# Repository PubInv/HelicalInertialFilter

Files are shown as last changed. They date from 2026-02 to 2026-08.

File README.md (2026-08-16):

# Helical Inertial Filter design

Through this project, we aim to design a filter that removes dust from low-velocity gas-solid suspensions which are characteristic of lunar surface systems, but could be used for regular medical purposes as well.

We have produced a physical helical filter prototype using 405nm UV-cured transparent resin surface-treated with polycrylic spray. We also tested the filter by installing one end in the “Particle Zenith Device”, described below, and the other end in an industrial shop vacuum. 

Currently, we are looking for additional volunteers with backgrounds in mechanical engineering and leadership to bring this project to the next level. If you are interested in joining the team, contact comms@pubinv.org or go directly to [this calendar](https://calendar.app.google/S1aWuwjtvq6XvQwG7) to schedule an interview.

## Basic Idea

A particle in a fluid forced through a helix feels a "centrifugal" force. If it is denser than the fluid, as most particulates in air are, it will be pushed to the ouside of the helix.
A slit or opening there may preferentially allow the particle, or particle-heavy fluid, to leave the helix.
The helix is thus acting as a simple "sorting" device. The remain fluid flow in the helix is cleaner than at was before the particle left.

Helices can be wound around each other and packed together to create compact geometries with many ports. This project is focusing, however, on optimizing a single helix
for now.

This has a great advantage of fiber-based filters. In a sense it does not clog---or at least it does not continually clog degrading its performance.
It may be possible to produce a filter that requires very low pressure difference to clean the air this way.
Finally, instead of the maintenance of replacing or cleaning the filter, the filter is in theory renewable by just dumping out the filtered particles.

A fully developed version of this filter could be very commercially valuable system on Earth and a safer system in Space.

## Testing the Filter with the Particle Zenith Device
NOTE: “Re-entrainment” is a significant problem in our design, which could affect the experimental performance reported below. 

We tested the effectiveness of the filter design using a range of particulate sizes by using two teaspoons of the following materials:

* powdered sugar (fine particle size distribution), 
* table salt (medium particle size distribution), 
* cornmeal (coarse particle size distribution), and 
* mineral salt (large particle size distribution).

We introduced these individually into the gas-solid suspension generator. The particle sizes varied from 50 μm (powdered sugar) to 1500 μm (mineral salt). Suspensions were generated by injecting compressed air at the base of the chamber with the Particle Zenith Device, forcing the particles into an upward flow and creating a circulating gas-solid suspension that passed through the helical inertial filter.  

In order to come as close as possible to simulating a low-gravity environment, the Particle Zenith Device projects particles upward in a semi-enclosed tube. It has a cone-shape funnel at the bottom attached to a source of pressurized air. This jet of air somewhat “fluidizes” the fallen particles, and blows them with a velocity nearly proportional to the air pressure. By adjusting the pressure, the maximum height of the particle, or zenith, can be partially controlled. 

At the zenith, the particle momentarily has a minimal velocity. When the inertial filter is placed at that height, it extracts particles as it would in a low gravity environment. The top is open, allowing air to flow out and balance the air injected by the compressor. However, since this is a relatively small flow, the top can be mostly covered.

Particles which hit the lid generally fall back down into the funnel to be recirculated. A small number of particles escape into the room or get sucked into the helical inertial filter. 

A sketch of this design is pictured below:

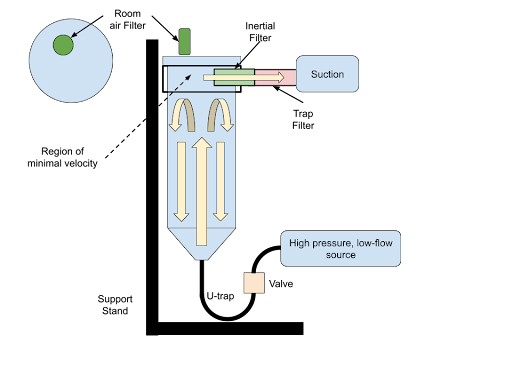
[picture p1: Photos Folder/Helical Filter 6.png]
Schematic diagram of the particle zenith device


Schematic diagram of the particle zenith device

Photos of the Particle Zenith Device are included below. The attachment in the middle is where the filter is inserted into the particle chamber. The far right image shows white (powdered sugar) gas-solid suspensions emerging at a low velocity. It is possible to quantify and engineer the dynamic behavior of the suspension at the region of minimal velocity to better align with practical uses in future research. Below is an image of the helical and paper filter stages loaded with cornmeal (which has a distinct color) and powdered sugar after experimental runs.

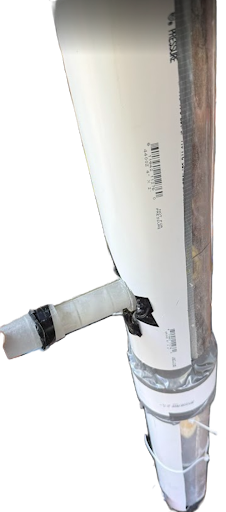
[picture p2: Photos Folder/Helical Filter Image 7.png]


Particle zenith device assembly.

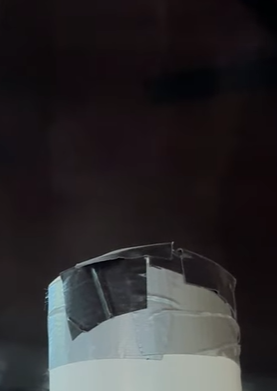
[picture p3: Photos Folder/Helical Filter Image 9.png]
Particle zenith device assembly and operation.


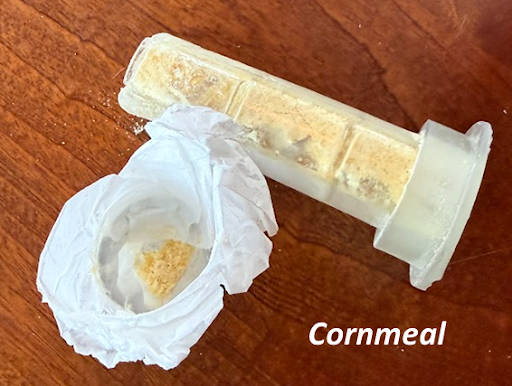
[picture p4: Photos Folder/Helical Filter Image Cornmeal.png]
Filter condition after experimenting with cornmeal.


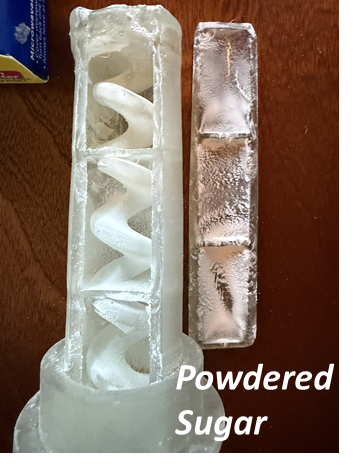
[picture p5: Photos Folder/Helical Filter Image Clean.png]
Filter condition after experimenting with powdered sugar.


Particle zenith device assembly and operation and filter condition after experimenting with cornmeal and powdered sugar.

## Results of the Tests

We collected the material that passed through the filter ("pass") and the material that successfully remained trapped in the helical filter. We measured the weight in grams using a lab-grade precision scale to quantify the pass rate (the percent of material that escaped through the filter). Each trial lasted for 120 seconds, and the vacuum pressure at the filter outlet (which is interlocked with the shop vacuum) was 1.75 PSI. The results are shown below.

| Material Type | Material Passed (g) | Total Material collected in filter (g) | Pass (%): Filtrate / Permeate| Caught (%): Residue / Retentate |
| --- | --- | --- | --- | --- |
| Powdered Sugar Trial 1 | 0.115 | 0.445 | 25.8 | 74.2 |
| Powdered Sugar Trial 2 | 0.115 | 0.296 | 38.9 | 61.1 |
| Powdered Sugar Trial 3 | 0.17 | 0.513 | 33.1 | 66.9 |
| Table Salt Trial 1 | 0.178 | 0.662 | 26.7 | 73.3 |
| Table Salt Trial 2 | 0.060 | 0.282 | 20.0 | 80.0 |
| Table Salt Trial 3 | 0.106 | 0.432 | 24.5 | 75.5 |
| Cornmeal Trial 1 | 0.862 | 2.984 | 28.8 | 71.2 |
| Cornmeal Trial 2 | 0.453 | 2.215 | 20.5 | 79.5 |
| Cornmeal Trial 3 | 0.501 | 2.454 | 20.4 | 79.6 |
| Mineral Salt Trial 1 | 0.050 | 0.219 | 22.8 | 77.2 |
| Mineral Salt Trial 2 | 0.076 | 0.283 | 26.9 | 73.1 |
| Mineral Salt Trial 3 | 0.128 | 0.487 | 26.3 | 73.7 |

We measured an average caught/retentate rate of 73.8% across all tested materials. These results indicate that the helical filter consistently retained the majority of the material regardless of particle size, with pass/filtrate rates remaining within a relatively narrow range (20.0-38.9%). 

This suggests that the helical geometry successfully induces inertial separation across a broad spectrum of particulate sizes. The relatively similar performance across materials may further suggest that filter geometry and flow dynamics, rather than particle size alone, are dominant factors that govern collection behavior in the current design. 

However, further study is needed to determine whether modifications to filter geometry, slit placement, chamber design, or operating conditions can reduce these losses, or whether they are inherent limitations of the helical filter architecture itself. This is one aspect of the project we are seeking to continue developing.

## Major Problem: Re-Entrainment

After this initial test, we isolated the filter with the shop vacuum attached and packed the filter chamber with cornmeal to test a “pre-loaded” filter in clean air. We ran the vacuum to assess what portion of material was re-entrained through the slits and collected this material in a paper filter. We observed a 16.2% pass, or re-entrainment, indicating that a substantial fraction of captured material remained susceptible to subsequent transport through the filter, limiting overall collection efficiency. 

## The Need for Continued Project Development 

These tests were completed during our initial contract with NASA, in tandem with the M-COG’s development. This work established the feasibility of helical inertial filtration for particulate capture in low-velocity gas-solid suspensions and provides direction for future investigation. While the current prototype demonstrated measurable particulate retention across a range of particle sizes, the observed pass and re-entrainment rates indicate opportunities for further optimization. 

Therefore, we will need to continue research and development of the filter to identify potential design improvements. Currently, this is our plan:

* First, we will run additional trials with each material. The first five trials will replicate the existing protocol to improve statistical confidence in the baseline results. In the additional tests, the filter will be rotated by 90° to evaluate whether slit orientation relative to gravity influences particulate capture efficiency and pass rate.
* Second, we will test two modified filter designs. One design will incorporate wider helical turns to alter particle trajectories and time within the filter. The second design will modify slit placement to evaluate the effect of extraction location on collection efficiency and re-entrainment behavior.
* Third, we will investigate the influence of the surrounding collection chamber geometry. Possible modifications include increasing the chamber depth, enlarging particulate collection regions, and incorporating additional passive collection features within the chamber walls. These modifications could reduce the likelihood of captured particles re-entering the airflow and subsequently clogging the filter.

## The Helical Filter

The OpenSCAD files in this repository are highly parameterized. The filter should not be considered one 3D printable module, but rather a toolkit or “design kit” for making models of any size, number of coils, slit geometries, etc. It aims to make testing new printable designs as easy as possible. Of course, this requires some understanding of the OpenSCAD programming language, and reading the code to understand the configuration. This design is captured in the figure below.

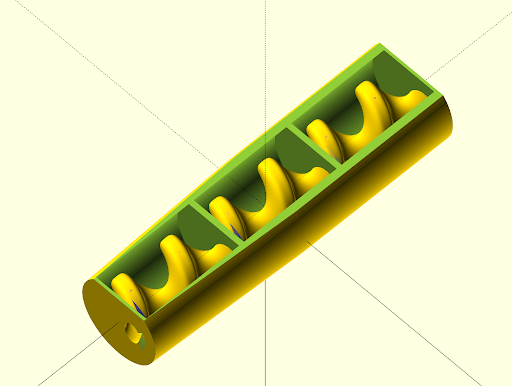
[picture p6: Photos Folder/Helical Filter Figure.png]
Highly parameterized OpenSCAD helical filter design


Highly parameterized OpenSCAD helical filter design

At present, this file produces a “cartridge” with a tapered cylinder which is convenient for testing within a standard vacuum cleaner or shop vac hoses. Below is pictured a 3-bin, 6-turn cartridge. A “cap” can be produced from the same file so that the bins are all closed.

In future work, we need to modify our design to have much deeper bins. The OpenSCAD system minimizes the labor of producing such a design. Included below is a photo of the filter ready to be plugged into a shop vac .

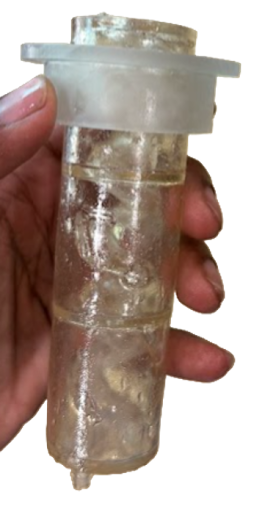
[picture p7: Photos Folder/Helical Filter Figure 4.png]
3D printed and assembled filter ready for installation.


3D printed and assembled filter ready for installation.

An early prototype looked like this:

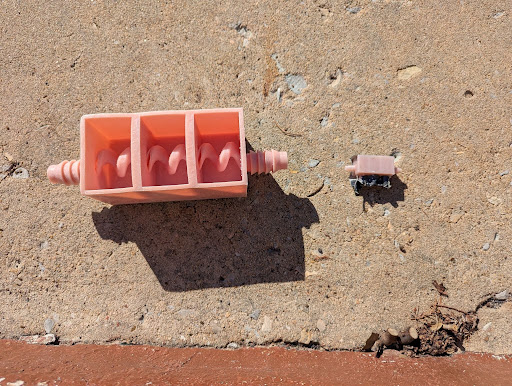
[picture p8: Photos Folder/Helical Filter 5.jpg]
Early prototypes which used barbed fittings


Early prototypes which used barbed fittings.

We altered this approach in favor of a system that did not use barbs because otherwise it became difficult to control the particulates in the tube.

# Bibliography
HEPA Filter Testing for Life Support Systems on Artemis Lunar Missions, accessed November 23, 2025, https://ttu-ir.tdl.org/bitstreams/01236268-2dc8-46ab-a3fe-6d9d5cbd9797/download

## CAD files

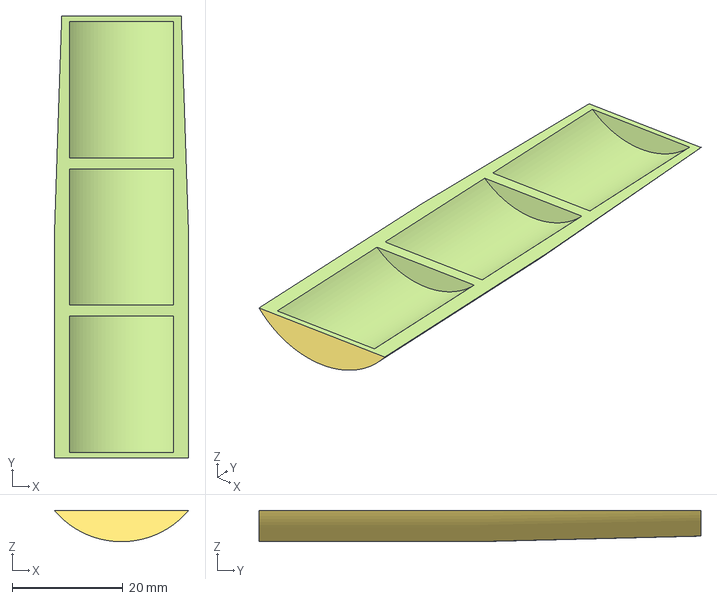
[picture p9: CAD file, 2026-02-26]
Printables/BinCapFeb26.3mf
24.3 x 80.0 x 5.67 mm

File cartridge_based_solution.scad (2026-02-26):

// This file is Copyright Robert L. Read 2025.
// Although Public Invention does everything open source, this file is an
// exception.

// MODIFIED by Gemini.
// VERSION 21: Corrected spacer alignment, helical void concentricity, and support visibility.

// --- Model Precision ---
high_res_fn = 150;
low_res_fn = 30;
$fn = $preview ? low_res_fn : high_res_fn;

// --- Main Parameters ---
num_bins = 3; 
number_of_complete_revolutions = 12;
screw_OD_mm = 1.8;
screw_ID_mm = 1;
scale_ratio = 1.4;

// --- NEW PARAMETERS for Tube Filter ---
tube_od_mm = 32;
tube_wall_mm = 1;
insert_length_mm = 350/2;
oring_cross_section_mm = 1.5;
spacer_height_mm = 5;
adapter_hose_id_mm = 30;
support_rib_thickness_mm = 2.5;
support_revolutions = 4;
support_density = 4; // NEW: Number of support bundles around the circumference
flange_od = 20;           // Outer diameter of the hose adapter flange
flange_height = 5;        // Height of the hose adapter flange

// --- Tolerances & Fit ---
// Adjust these values based on your printer's calibration
tolerance_tube_fit = 0.2;   // Clearance between the spacers and the inner wall of the tube
tolerance_socket_fit = 0.4; // Clearance between the screw and the spacer socket
tolerance_channel = 0.1;  // Extra clearance for the airflow channel to prevent binding

// --- Config File ---
// Include a configuration file to override the default parameters below.
config_file = "default.scad";
include <config_file>

// --- CONTROL_VARIABLES ---
GENERATE_CFD_VOLUME   = false; // NEW: Set to true to generate the internal fluid volume for CFD analysis
USE_MASTER_HELIX_METHOD = true; // NEW: Switch between assembly strategies
USE_MODULAR_FILTER    = 1;
USE_HOSE_ADAPTER_CAP  = 0;
THREADED_INLET        = false ;

// Visual Options
ADD_HELICAL_SUPPORT   = true;
USE_TRANSLUCENCY      = false;
SHOW_O_RINGS          = true;

// ===============================================================
// === Main Logic ================================================
// ===============================================================

if (GENERATE_CFD_VOLUME) {
    tube_id = tube_od_mm - (2 * tube_wall_mm);
    difference() {
        // 1. Start with a solid cylinder representing the inner volume of the tube
        cylinder(d = tube_id, h = insert_length_mm, center = true);
        
        // 2. Subtract the entire filter assembly
        ModularFilterAssembly(tube_id, insert_length_mm, num_bins, spacer_height_mm, oring_cross_section_mm);
    }
} else {
    // Logic to generate the solid parts for printing
if (USE_MODULAR_FILTER) {
    if (USE_MASTER_HELIX_METHOD) {
        // New, more robust assembly method
        ModularFilterAssembly(tube_od_mm - (2 * tube_wall_mm), insert_length_mm, num_bins, spacer_height_mm, oring_cross_section_mm);
    } else {
        // Old method kept for debugging
        ModularFilterAssembly_Rotational(tube_od_mm - (2 * tube_wall_mm), insert_length_mm, num_bins, spacer_height_mm, oring_cross_section_mm);
    }
} else if (USE_HOSE_ADAPTER_CAP) {
    HoseAdapterEndCap(tube_od_mm, adapter_hose_id_mm, oring_cross_section_mm);
}
}


// ===== Rob's definitions ======

// coordinate system: Gravity points in the -Z direction. +Z is up.abs
// The left-right dimentions is considered X. Air flow is in the positive Y
// direction. The is a right-handed coordinate system.

module Corkscrew(h,twist) {
    rotate([90,0,0])
    linear_extrude(height = h, center = true, convexity = 10, twist = twist, $fn = FN_RES)
    translate([screw_OD_mm, 0, 0])
    scale([1,scale_ratio])
    circle(r = screw_OD_mm);
}

//module CorkscrewSlitKnife(twist,depth,num_bins) {
//    de = depth/num_bins;
//    yrot = 360*(1 / pitch_mm)*de;
//    
//    // Note: The computation of the slit angle 
//    // is a complicated. We create a triangle that 
//    // we linearly extruide (in the "polygon" state below.)
//    D = 5*screw_OD_mm;
//    W = D * tan(slit_knife_angle);
// //   translate([10,0,0])
////    polygon(points = [[0,0],[D,-W],[D,W]]);   
//    echo("twist",twist);
//    echo("W",W);
//    echo("yrot",yrot);
//    echo("de",de);
//    echo("slit_axial_length_mm",slit_axial_length_mm);
//    echo("screw_OD_mm",screw_OD_mm);
//    echo("num_bins",num_bins);
//    echo("depth",depth);
//    echo("FN_RES",FN_RES);
//    rotate([90,270,0])
//    for(i = [0:num_bins -1]) {
//        translate([0,0,-de])
//        rotate([0,0,-yrot*(i+1)])
//        translate([0,0,(i+1)*de])
//        difference() {
//            linear_extrude(height = depth, center = true, convexity = 10, twist = twist, $fn = FN_RES)
//            translate([screw_OD_mm,0,0])
//            rotate([0,0,0])
//            polygon(points = [[0,0],[D,-W],[D,W]]);   
//            color("blue",0.3)
//            translate([0,0,slit_axial_length_mm])
//            cylinder(d=screw_ID_mm*8,h=depth,center=true);
//        }
//    }
//    
//}
module CorkscrewSlitKnife(twist,depth,num_bins) {
    de = depth/num_bins;
    yrot = 360*(1 / pitch_mm)*de;
    
    // Note: The computation of the slit angle 
    // is a complicated. We create a triangle that 
    // we linearly extruide (in the "polygon" state below.)
    D = 20;
    W = D * tan(slit_knife_angle); 
    echo("twist",twist);
    echo("W",W);
    echo("yrot",yrot);
    echo("de",de);
    echo("slit_axial_length_mm",slit_axial_length_mm);
    echo("screw_OD_mm",screw_OD_mm);
    echo("num_bins",num_bins);
    echo("depth",depth);
    echo("FN_RES",FN_RES);
    echo("pitch_mm",pitch_mm);
    // This should be the position of the helix at the "end"
    // where we need to start the slit.
    angle_of_knife_at_end = depth * 360 / pitch_mm;
    echo("angle_of_knife_at_end",angle_of_knife_at_end);
    rotate([90,0,0])
    for(i = [0:num_bins -1]) {
        translate([0,0,-de])
        rotate([0,0,-yrot*(i+1)])
        translate([0,0,(i+1)*de])
        difference() {
            linear_extrude(height = depth, center = true, convexity = 10, twist = twist, $fn = 200)
            rotate([0,0,angle_of_knife_at_end])
            translate([screw_OD_mm,0,0])
            polygon(points = [[0,0],[D,-W],[D,W]]);   
            color("blue",0.3)
            translate([0,0,slit_axial_length_mm])
            cube([150,150,depth],center=true);
        }
    }
    
}


module CorkscrewWithVoid(h,twist) {
    rotate([90,0,0])
    linear_extrude(height = h, center = true, convexity = 10, twist = twist, $fn = FN_RES)
    translate([screw_OD_mm, 0, 0])
    difference() {
        scale([1,scale_ratio])
        circle(r = screw_OD_mm);
        scale([1,scale_ratio])
        circle(r = screw_ID_mm);
    }
}
module CorkscrewVoid(h,twist) {
    rotate([90,0,0])
    linear_extrude(height = h, center = true, convexity = 10, twist = twist, $fn = FN_RES)
    translate([screw_OD_mm, 0, 0])
    scale([1,scale_ratio])
    circle(r = screw_ID_mm);
}

module CorkscrewWithoutVoid(h,twist) {
    echo("CorkscrewWithoutTwist");
    echo(scale_ratio);
    rotate([90,0,0])
    linear_extrude(height = h, center = true, convexity = 10, twist = twist, $fn = FN_RES)
    translate([screw_OD_mm, 0, 0])
    scale([1,scale_ratio])
    circle(r = screw_OD_mm);
}

module CorkscrewWithoutVoidExcess(h,twist) {
    CorkscrewWithoutVoid(h*2,twist*2);
}
module CorkscrewInnerVoidVoidExcess(h,twist) {
    CorkscrewVoid(h*2,twist*2);
}


module CorkscrewWithSlit(depth,numbins) {
    echo("Filter_twist_degrees",filter_twist_degrees);
      difference() {
       CorkscrewWithVoid(depth,filter_twist_degrees);
        echo("spud");
        CorkscrewSlitKnife(filter_twist_degrees,depth,numbins);
    }
}




// ===============================================================
// === Module Definitions ========================================
// ===============================================================

// Unified module to generate a helical shape with a given radius.
// This ensures the solid and void helices are generated with identical logic.
module HelicalShape(h, twist, r) {

    echo(str("Generating HelicalShape: r=", r, ", center=[", screw_OD_mm, ", 0, 0]"));
    linear_extrude(height = h, center = true, convexity = 10, twist = twist) {
        translate([screw_OD_mm, 0, 0]) {
            scale([1, scale_ratio]) {
                circle(r = r);
            }
        }
    }

}

// Creates the helical cutting tool for the void.
module CorkscrewVoid(h, twist) {
    HelicalShape(h, twist, screw_ID_mm + tolerance_channel);
}

// This module creates the solid part of the helical screw.
module CorkscrewSolid(h, twist) {
    HelicalShape(h, twist, screw_OD_mm);
}

// Assembles the complete filter using the "Master Helix" method for robust alignment.
module ModularFilterAssembly(tube_id, total_length, bin_count, spacer_h, oring_cs) {
    total_spacer_length = (bin_count + 1) * spacer_h;
    total_screw_length = total_length - total_spacer_length;
    bin_length = total_screw_length / bin_count;
    twist_rate = (360 * number_of_complete_revolutions) / total_length;
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

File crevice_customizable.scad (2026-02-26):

// How thick should the shaft be to fit your vaccuum?
shaft_diameter = 32; // [10:60]

// How wide should the tip of the nozzle open?
nozzle_opening = 8; // [1:20]

// How long should the crevice be in total?
crevice_length = 100; // [100:500]

// How thick should the walls of the nozzle be? (Thinner = less filament usage but more likely to break)
wall_thickness = 3; // [1:10]

module shape(rohrdurchmesser, duesenstaerke, laenge){
		
	difference(){		
		union(){
			cylinder(laenge/2, r=rohrdurchmesser/2);
			intersection(){
					translate([-rohrdurchmesser/2,-duesenstaerke/2,laenge/2]) 
						cube([rohrdurchmesser,duesenstaerke,laenge/2]);
					translate([0,0,laenge/2]) 
						cylinder(laenge/2, r=rohrdurchmesser/2);
			}
		}
		for(i = [[-rohrdurchmesser/2,-laenge/2-duesenstaerke/2,laenge/2],[-rohrdurchmesser/2,laenge/2+duesenstaerke/2,laenge/2]])			
			translate(i)
			rotate([0,90,0]) 
			cylinder(rohrdurchmesser, r=laenge/2);
	}
}

module fugenduese(rohrdurchmesser, duesenstaerke, laenge, wandstaerke){
$fn = 200;
blocklaenge = sqrt(pow((rohrdurchmesser+2*wandstaerke)*3/4,2)*2);
	difference(){
		shape(rohrdurchmesser+wandstaerke*2,duesenstaerke+wandstaerke*2,laenge); // duese erstellen

		translate([0,0,0]) shape(rohrdurchmesser,duesenstaerke,laenge); //duese aushoehlen

		translate ([(rohrdurchmesser+2*wandstaerke)/4,0,laenge])
	   rotate([0,-45,0]) translate([-blocklaenge,-(duesenstaerke+wandstaerke*2)/2-0.005,0]) cube([blocklaenge,duesenstaerke+wandstaerke*2+0.01,blocklaenge]); //im 45Grad Winkel abschneiden

		difference(){ 

			translate([(rohrdurchmesser+2*wandstaerke)/8+(rohrdurchmesser+2*wandstaerke)/16,-(duesenstaerke+2*wandstaerke)/2-0.005,laenge-(rohrdurchmesser+2*wandstaerke)/8/4+0.005]) cube([(rohrdurchmesser)/8, duesenstaerke+2*wandstaerke+0.01 ,(rohrdurchmesser+2*wandstaerke)/8/4+0.005]);

			translate([
(rohrdurchmesser+2*wandstaerke)/4+(((rohrdurchmesser)/8)-sqrt(pow((rohrdurchmesser+2*wandstaerke)/8,2))/2),
duesenstaerke/2+wandstaerke+0.01,
laenge-(rohrdurchmesser+2*wandstaerke)/8]) 
rotate([90,0,0]) cylinder(duesenstaerke+wandstaerke*2+0.02, r = (rohrdurchmesser+2*wandstaerke)/8);

		} // die Ecke der Schnittkante abrunden
	}


}

// fugenduese(shaft_diameter,nozzle_opening,crevice_length,wall_thickness);

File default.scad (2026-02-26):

// Thirsty Corkscrew - Default Configuration File
//
// To create a new configuration, copy this file, rename it,
// and change the `config_file` variable in `corkscrew filter.scad`
// to point to your new file.

// --- Main Parameters ---
num_bins = 1;
number_of_complete_revolutions = 12;
screw_OD_mm = 1.8;
screw_ID_mm = 1;
scale_ratio = 1.4;

// --- NEW PARAMETERS for Tube Filter ---
tube_od_mm = 32;
tube_wall_mm = 1;
insert_length_mm = 350/2;
oring_cross_section_mm = 1.5;
spacer_height_mm = 5;
adapter_hose_id_mm = 30;
support_rib_thickness_mm = 1.5;
support_density = 4;
flange_od = 20;
flange_height = 5;

// --- Tolerances & Fit ---
tolerance_tube_fit = 0.2;
tolerance_socket_fit = 0.4;
tolerance_channel = 0.1;

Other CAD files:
HelicalIntertialFilter.scad
ThirstyCorkscrew.scad

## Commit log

2025-11-08 fixing bug in knife angle, I think
    [corkscrew filter.scad, default.scad]
2026-02-25 minor change to remove bins
    [ThirstyCorkscrew.scad]
2026-02-25 Just trying to get this to merge; I have no intention of using this file.
    [corkscrew filter.scad]
2026-02-25 restoring code
    [ThirstyCorkscrew.scad]
2026-02-26 attempting to produce 3D printable system
    [BinCapFeb26.3mf, ThirstyCorkscrew.scad, corkscrew filter.scad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]
2026-03-03 trying to make a working part
    [ThirstyCorkscrew.scad]
2026-06-19 minor tweaks
    [HelicalIntertialFilter.scad, cartridge_based_solution.scad]
